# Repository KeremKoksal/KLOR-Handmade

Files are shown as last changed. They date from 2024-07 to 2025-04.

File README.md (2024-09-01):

# Welcome to my take on the great KLOR Split Keyboard Project
Here you'll find an up do date version of KLOR PCB and firmware files for Rev 1.4 for full height Cherry switches and a Rev 1.4 LP KS33 version for low profile KS33 Gateron switches.

If you intend to build a KLOR keyboard from this repo please take the time to read the different sections below.

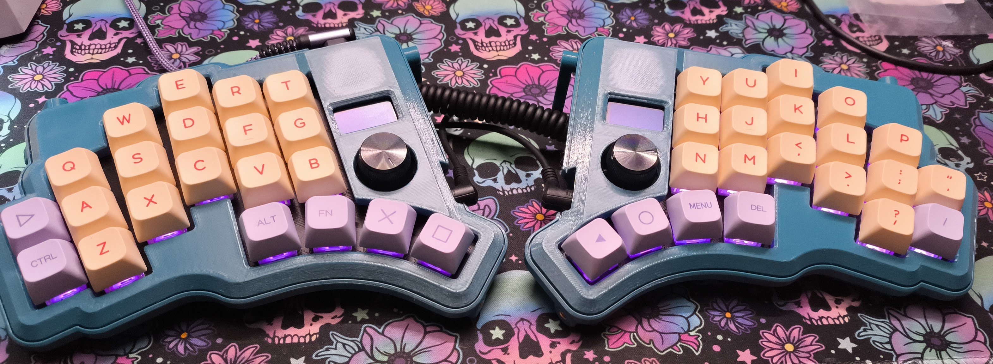
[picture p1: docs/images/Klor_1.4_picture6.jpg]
KLOR

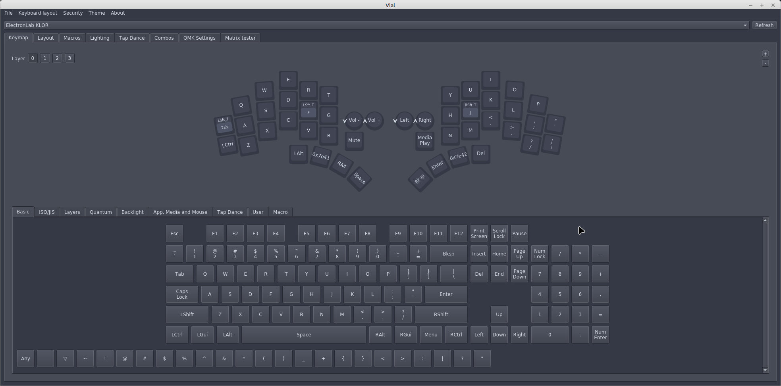
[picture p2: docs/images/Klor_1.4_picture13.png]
KLOR


### [CHANGELOG](https://github.com/Lefuneste83/KLOR/blob/main/CHANGELOG.md)

### [PCB FOR FULL HEIGHT SWITCHES (REV 1.4)](https://github.com/Lefuneste83/KLOR/tree/main/PCB/klor1_4)
-  This is my original initial design, derived from the 1.3 with lots of upgrades. I have built it and it works great. The south facing LED and the better suited LED packages make this the best choice for a first KLOR build. It keeps the overall design of the original in terms of PCB size and modularity. It is designed for MX style full height hotswap sockets. Gateron or Kailh sockets work great and probably other brands as well. This is not compatible with low profile sockets!

### [FABRICATION NOTES (FOR REV 1.4)](https://github.com/Lefuneste83/KLOR/blob/main/FABNOTES.md)
- These are my recommendations for first time builders of the KLOR keyboard. I suggest to have a read as they explain most tricky points that I have encountered while building mine.

### [PCB FOR LOW PROFILE GATERON KS33 SWITCHES (BETA VERSION REV 1.4 LP KS33)](https://github.com/Lefuneste83/KLOR/tree/main/PCB/klor1_4_LP_KS33)
-  This is a beta version derived from the 1.4 using low profile Gateron hotswap sockets for KS33 switches. It is a beta version so it will see lots of updates in the coming days. Don't rush to have it made except if you want to test it. In particular the haptic module will most likely interfere with the sockets and will require some filing of the haptic PCB. So it is not perfect yet.

### [PCB FOR ALTERNATIVE HAPTIC MODULE](https://github.com/Lefuneste83/KLOR/tree/main/PCB/Alternate%20DIY%20Haptic%20Module)
-  This is an alternative version of the haptic module for those who don't want to spend a fortune on the original one or can't source it. It is for advanced users as you will need some experience in SMD soldering and a hot air or hot plate to solder the linear actuator, and some form of magnification for the driver chip. It works great and is a bit shorter for easier integration. It mounts perfectly on all PCB versions except most likely on the low profile PCB because of the interference with the hotswap socket.

### [PCB FOR FULL HEIGHT SWITCHES CORRECTED STOCK VERSION (REV 1.3)](https://github.com/Lefuneste83/KLOR/tree/main/PCB/klor1_3)
-  This is as close as it gets to the original design but with some rerouting to allow to pass JLCPCB preproduction validation process. It uses the older style of LED (WS2812 3535) which are very tricky to solder properly, as they are not intended to be mounted this way. I strongly suggest moving to the 1.4 version for a much better build experience and a much more reliable build.

### [FIRMWARE](https://github.com/Lefuneste83/KLOR/blob/main/FIRMWARE.md)
-  VIAL support is now working on RP2040 with VIAL-QMK
-  These are updated QMK and ZMK config files and compiled images. They should have most devices enabled by default and should compile on latest toolchains of ZMK and QMK. A [Github Actions repositiry for ZMK](https://github.com/Lefuneste83/zmk-config-klor) is also available in my other repositories. Keep in mind that I only use ZMK on NRF52840 and QMK on RP2040. I would advise you to do the same as Atmega chips will not support all functionalities of the KLOR keyboard. As a reminder ZMK on NRF52840 will not support audio or haptic yet, but will support OLED to a certain degree and wireless communications with BLE protocol. QMK on RP2040 will support everything except wireless communications.

# CONTEXT
I have just completed my build of the 1.3 and found it a bit frustrating to assemble, despite my 13 year experience with this kind of project. Don't get me wrong the KLOR project is absolutely marvelous, but the PCB design starts to show its age IMHO, in the details of the layout in particular. Technology wise it is one, if not the best project out there hands down.

So here you will find a completely refactored PCB design of the KLOR project for 2024 including :

- Much better suited and easier to solder ARGB modules. I have used SK6812 Mini-E (aka 6028 size LED) version as it is the typical choice for this kind of keyboard application. I have thus kept the original paradigm of through hole design, with a symetrical front/back layout, but while using a LED module which is designed for this application, contrary to the original model WS2812 3535 which required a direct "hanged" soldering, with very likely damages to the plastic package as well as missalignment issues, as this part is designed for direct surface mount. I personnaly think that it would be even better to use the new WS2812 2020 package which is very neat, but as this is a strictly SMD part, there is no need for discrete cutouts anymore, so the design would look a bit different. Also you need to master SMD soldering. Let me know if you are interested in this type of LED package, I could make a forked design without too much fuss.

- As Hipyo Tech can confirm, we are in 2024 so no North facing LED are allowed anymore. I have moved to South facing LED.

- I have tried to keep the overall design paradigm so all the good stuff is still there!!

- I have very extensively refactored the PCB layout (3 days of intense work) to clean up the various little issues that were sprinkled around the original design including :

  Rerouting of 90% of the PCB. Healthier and more rational overall routing, at least that's my belief...
  
  Change to the footprint of the solder jumpers to triangular shapes much easier to bridge
  
  Correction of missing ground connections on the various switches bodies
  
  Dual ground planes thorough validation (this was painful)
  
  Very slight changes to the board cutout on the right side, to deal with reversed switch placement. Also very slight reduction of the cutout under the top of the MCU to catter some track celearance that would pop up in DRC. This should have no impact as this cutout serves no real purpose as far as I know. Cases and switchboards should mount the same, except for the ones using the puck cutout (see below).
  
  Very slight movement of the puck mounting holes downward (98.57 mm instead of 96.4 mm) by a couple milimeters to catter for reversed switches pad postions. I could not do otherwise without revisiting the switch layouts. I could not solve this by rotating the 3 mounting holes without interfering with other nets. It should not affect the mounting ability of the puck itself, but it WILL interfere with existing back cases using the puck cutout. So we will need specific cutouts for the case. As I don't have access to the original step model the best option would be to use some alternate case design provided with source files in order to lower the cutout by the same amount (2.17 mm).
  
  I managed a 0 error JLCPCB DRC, with only very few voluntary exceptions (down from 1000+). It took me several hours to clean up the various little issues that were sprinkled all around the orignial design. And I can confirm that Kicad on Linux is not a pleasure to use...
  
  Change of Logo with mine !

  This repo will be updated as I have new ideas for integrations of various tech or correction for errors.

  I have also included files for a working 1.3 design which passes the JLCPCB fabrication and is working as a real world product (REV 1.3)
  
***

<picture>
  <source media="(prefers-color-scheme: dark)" srcset="/docs/images/klor-font-logo-dark.svg">
  <source media="(prefers-color-scheme: light)" srcset="/docs/images/klor-font-logo-bright.svg">
  KLOR logo font
</picture>

# KLOR SPLIT KEYBOARD

KLOR is a 36-42 key column-staggered split keyboard. It supports a per-key RGB matrix, encoders, OLED displays, haptic feedback, speakers, a Pixart Paw3204 trackball, the [SplitKB tenting puck](https://splitkb.com/products/tenting-puck), and four different layouts, through break-off parts.

***

## RENDERING OF THIS FORK (Rev 1.4)

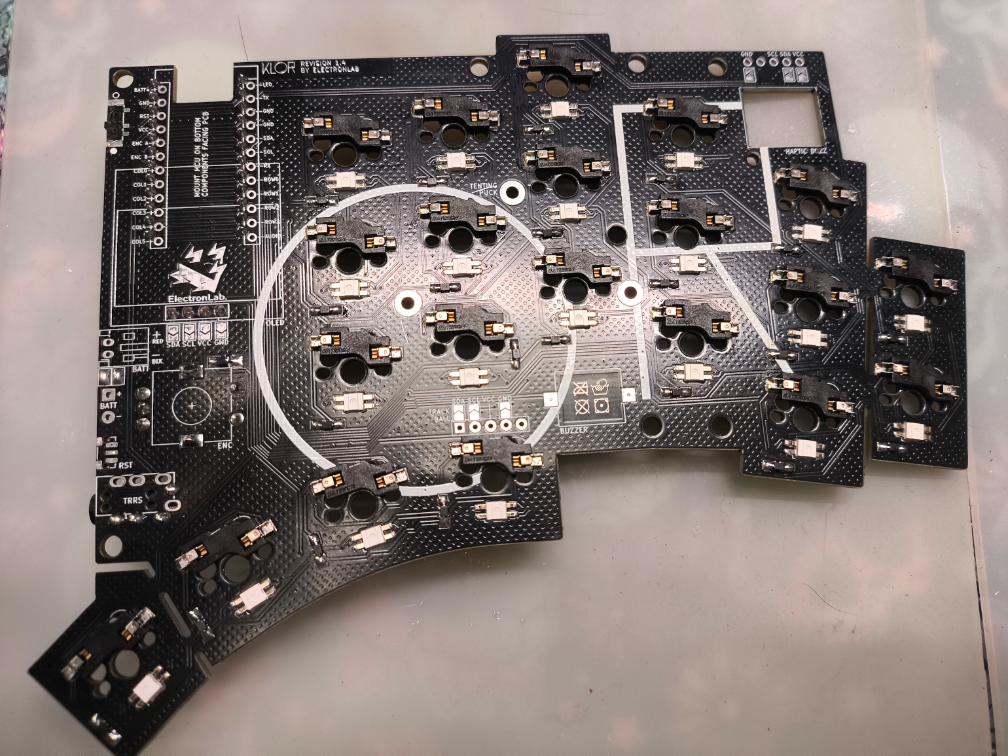
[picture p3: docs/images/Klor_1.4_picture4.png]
KLOR layouts

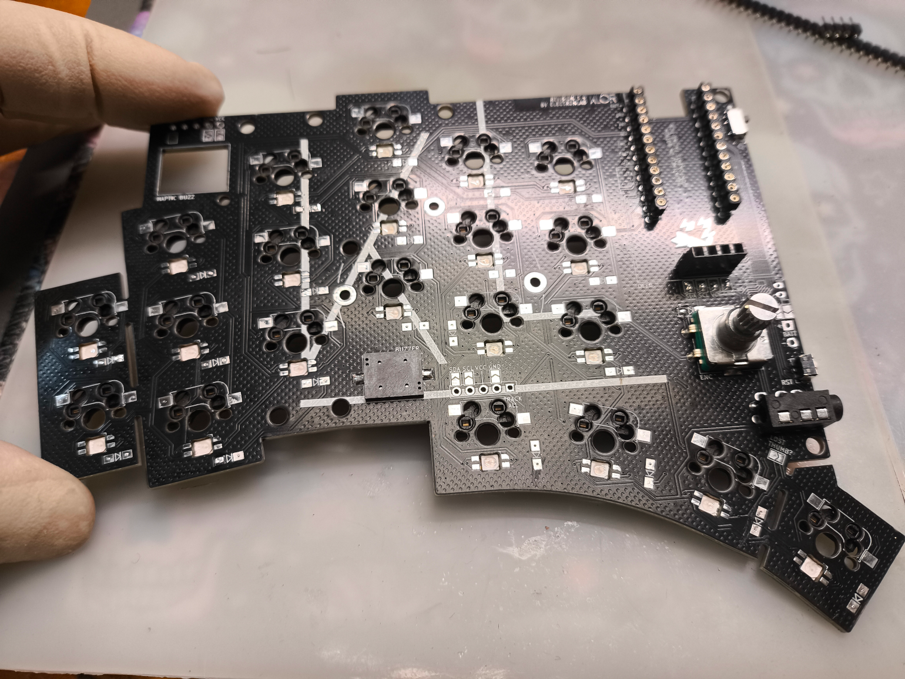
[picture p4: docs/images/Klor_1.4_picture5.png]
KLOR layouts

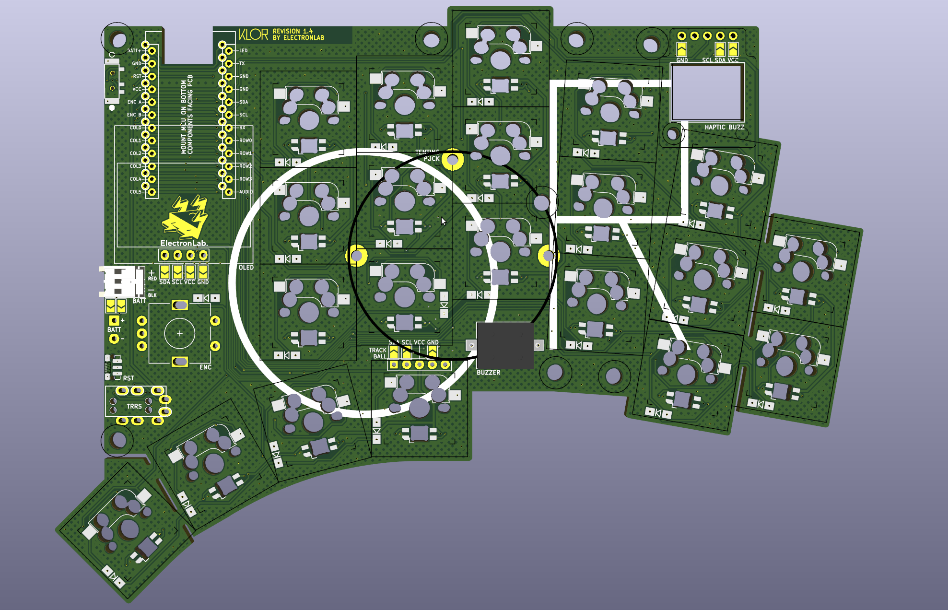
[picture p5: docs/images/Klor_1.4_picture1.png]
KLOR layouts

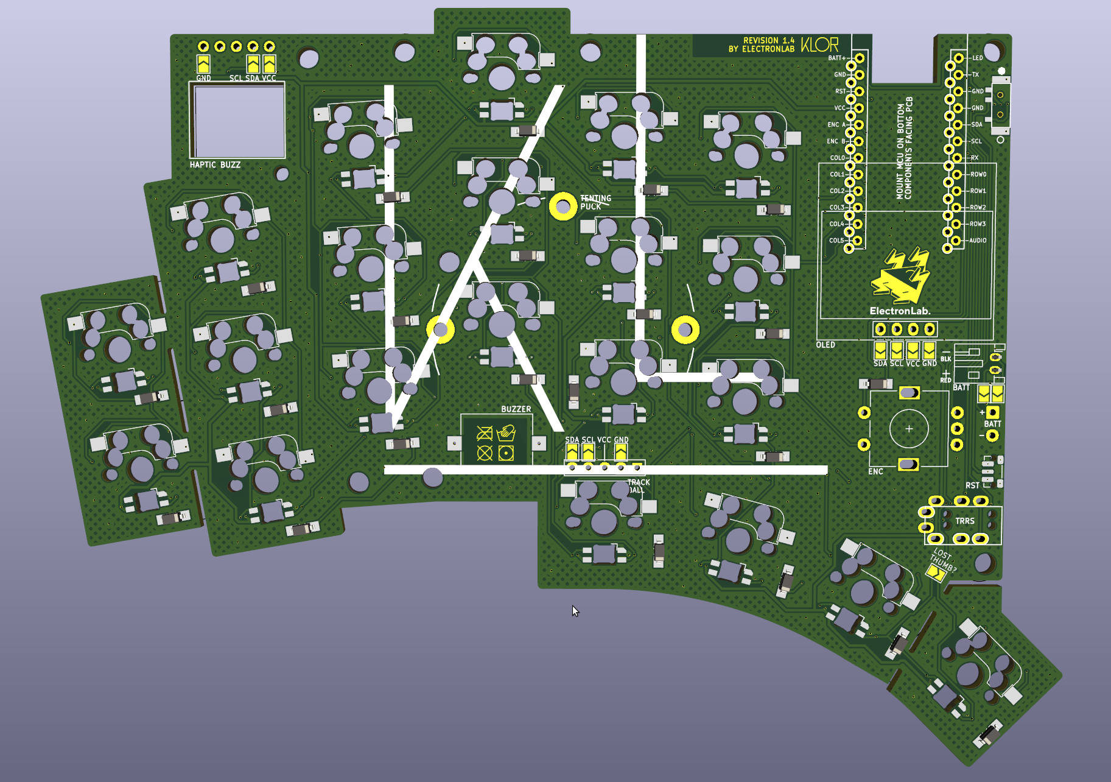
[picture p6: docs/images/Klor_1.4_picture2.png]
KLOR layouts

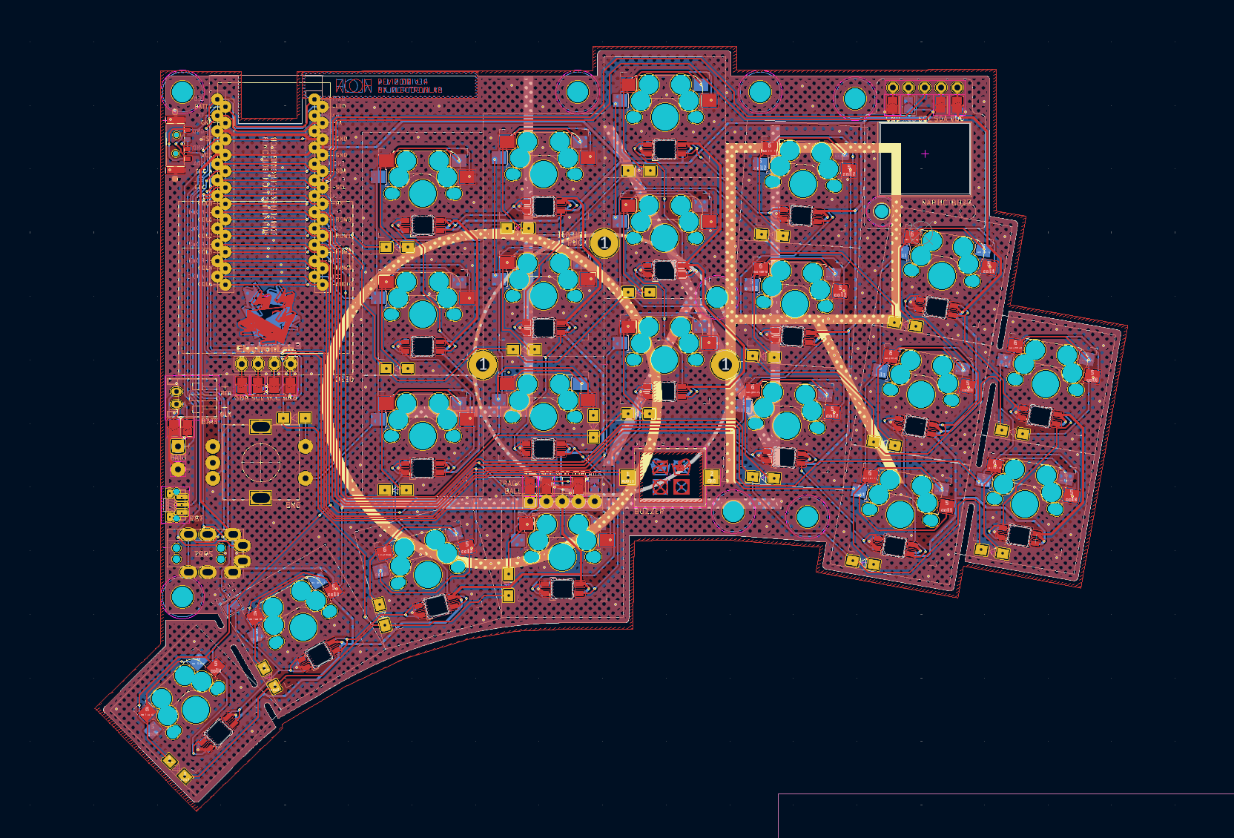
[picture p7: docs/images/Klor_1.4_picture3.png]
KLOR layouts


***

## LAYOUTS

KLOR layouts

***

## PCB 

[Here](/PCB/) you can find the KiCad files and Gerbers for the KLOR 1.3 (tested working with JLCPCB) and 1.4 (this version). 

***

## CASE

[Here](/case/) are the case files for the KLOR. There is an acrylic case and a 3D printed case (which uses acrylic too) for every layout.

***

## SWITCHPLATE

In every case directory you'll find the matching switchplates as **.dxf**, **.svg**, **.stl**, and a **.zip**-file, containing gerber files for a FR4 plate.

***

## KNOB

You can use pretty much any knob, which works with the EC11 encoder, but [here](/knob/) you can find one, I designed for the KLOR.

***

## BUILD GUIDE

Here you can find the build guides for the KLOR.\
[KLOR build guide 3DP case](/docs/buildguide_3DP.md) (QMK)\
[KLOR build guide stacked acrylic case](/docs/buildguide_acrylic.md) (QMK)\
[KLOR BLE build guide 3DP case](/docs/buildguide_3DP_ble.md) (ZMK)\
[KLOR BLE build guide stacked acrylic case](/docs/buildguide_acrylic_ble.md) (ZMK)

***

## CHOC/KS27 VERSION

[Sadek Baroudi](https://github.com/sadekbaroudi) did an amazing job in creating a version of the KLOR which supports KS-27 and Choc V1 switches. Including a special case for it.\
[KLOR Sadek KS-27 and Choc V1 mod](https://github.com/sadekbaroudi/KLOR)

***

## CREDITS

The KLORs hardware is based on the [Sofle](https://github.com/josefadamcik/SofleKeyboard) by [Josef Adamcik](https://github.com/josefadamcik).\
Other inspirations are 
- [Kyria](https://splitkb.com/products/kyria-pcb-kit) by [Thomas Baart](https://github.com/splitkb)
- [Yacc46](https://github.com/1m38/keyboards/tree/main/yacc46) by [1m38](https://github.com/1m38)
- [Elephant42](https://github.com/illness072/elephant42) by [illness072](https://github.com/illness072)
- [Torn](https://github.com/rtitmuss/torn) by [Richard Titmuss](https://github.com/rtitmuss)
- [Claw44](https://github.com/yfuku/claw44) by [yfuku](https://github.com/yfuku)

I used the Pimoroni Haptic Buzz Footprint from the [Buzzard](https://github.com/crehmann/Buzzard) by [Christoph Rehmann](https://github.com/crehmann).

***

People who helped me create this board and fix stuff
- [KarlK90](https://github.com/KarlK90)
- [MangoIV](https://github.com/MangoIV)
- [OxCB](https://github.com/0xCB-dev)
- [MicroFortnight](https://github.com/microfortnight)
- [dreipunkteinsvier](https://github.com/dreipunkteinsvier)

If you build a KLOR I would be pretty happy to see some pictures. And if you want to leave me a tip you can do this [here](https://ko-fi.com/geigeigeist) (but please don't feel pressured)

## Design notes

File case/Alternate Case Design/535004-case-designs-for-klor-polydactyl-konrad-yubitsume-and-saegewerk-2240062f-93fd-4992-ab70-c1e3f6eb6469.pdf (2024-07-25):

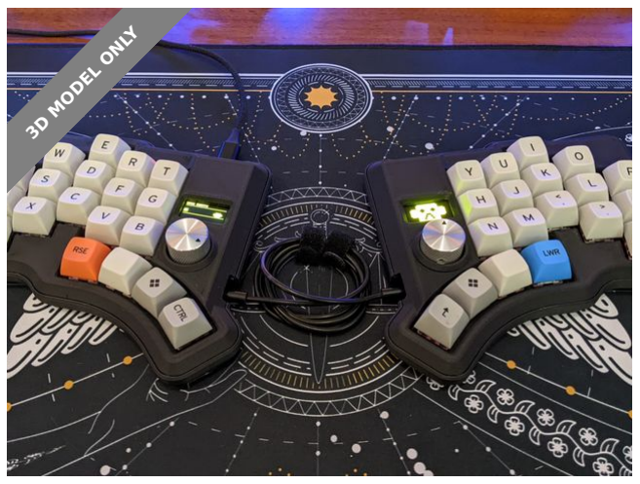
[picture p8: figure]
3D MODEL ONLY

## Summary

This is a case design for all four variants of the KLOR by GEIST

Gadgets (https://printables.com/model?categoryId=21) > Other Gadgets (https://printables.com/model?categoryId=43)

These are gasket mount case designs with optional tenting for KLOR. All four variants are supported. The top and bottom pieces fasten with 6mm x 3mm neodymium magnets. The optional tenting fastens via M3 heatset inserts. The lid pieces support encoder knobs up to 24mm. There are encoder inserts to accommodate knobs of a smaller diameter (20mm and 16mm).

IMPORTANT: The case design requires the MCU be mounted on TOP of the PCB with its components facing up. MCU sockets are recommended. The OLED screens were mounted with IC SIP sockets to allow it to be mounted low enough to fit in the case. Some low profile MCU sockets would also suffice.

M3 Inserts: https://www.amazon.com/gp/product/B09ZNXRD2H/ref=ppx_yo_dt_b_search_asin_title?ie=UTF8&th=1 (https://www.amazon.com/gp/product/B09ZNXRD2H/ref=ppx_yo_dt_b_search_asin_title?ie=UTF8&th=1)

Magnets: https://www.amazon.com/DIYMAG-6x3mm-Refrigerator-Premium-Brushed/dp/B07KZQGWNN (https://www.amazon.com/DIYMAG-6x3mm-Refrigerator-Premium-Brushed/dp/B07KZQGWNN)

chewiedies (https://printables.com/@chewiedies_360738)

## Case designs for

KLOR (Polydactyl,
Konrad, Yubitsume,

## and Saegewerk,)

VIEW IN BROWSER (https://printables.com/model/535004-case-designs-for-klor-polydactyl-konrad-yubitsume)

updated 2. 7. 2024 | published 2. 7. 2024

## Model files

3mm Foam: https://www.amazon.com/Neoprene-Adhesive-Padding-Multi-Function-Soundproof/dp/B08RB2FWVR/?th=1 (https://www.amazon.com/Neoprene-Adhesive-Padding-Multi-Function-Soundproof/dp/B08RB2FWVR/?th=1)

1mm Foam: https://www.amazon.com/gp/product/B07L6KV4QG/ref=ppx_yo_dt_b_search_asin_title?ie=UTF8&psc=1 (https://www.amazon.com/gp/product/B07L6KV4QG/ref=ppx_yo_dt_b_search_asin_title?ie=UTF8&psc=1)

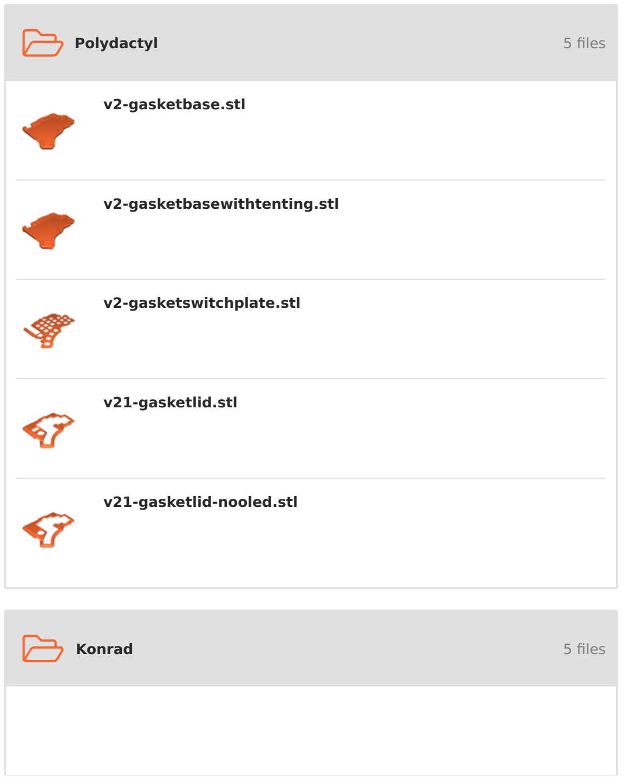
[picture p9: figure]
Polydactyl; 5 files; Konrad; v2-gasketbase.stl; v2-gasketbasewithtenting.stl; v2-gasketswitchplate.stl; v21-gasketlid.stl; v21-gasketlid-nooled.stl

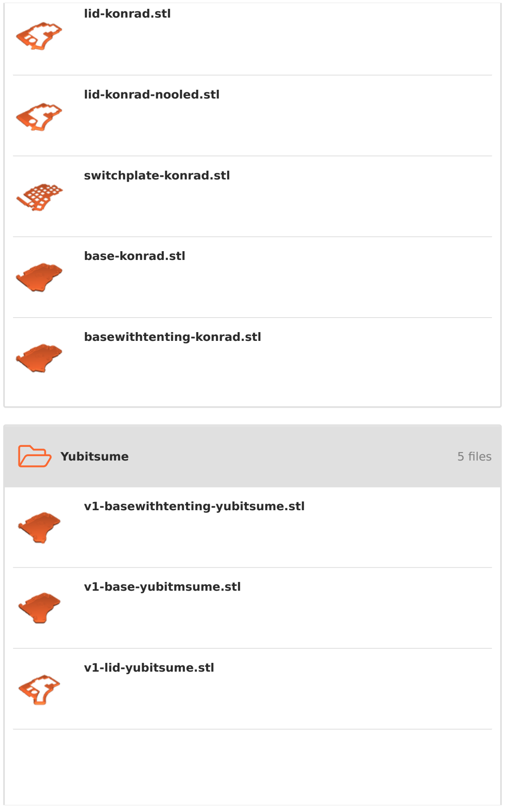
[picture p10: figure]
Yubitsume; 5 files; lid-konrad.stl; lid-konrad-nooled.stl; switchplate-konrad.stl; base-konrad.stl; basewithtenting-konrad.stl; v1-basewithtenting-yubitsume.stl; v1-base-yubitmsume.stl; v1-lid-yubitsume.stl

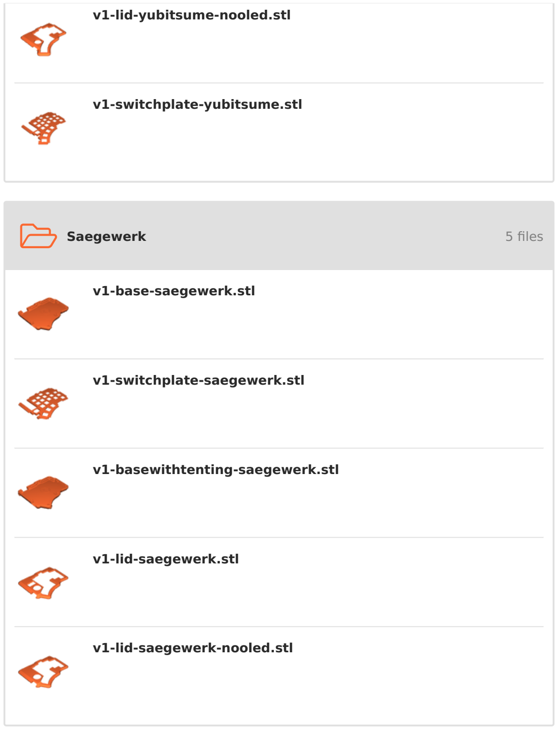
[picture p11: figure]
Saegewerk; 5 files; v1-lid-yubitsume-nooled.stl; v1-switchplate-yubitsume.stl; v1-base-saegewerk.stl; v1-switchplate-saegewerk.stl; v1-basewithtenting-saegewerk.stl; v1-lid-saegewerk.stl; v1-lid-saegewerk-nooled.stl

encoderinsert-flat-16mm.stl

## License

This work is licensed under a
Creative Commons (4.0 International License)

Attribution—Noncommercial—Share Alike (http://creativecommons.org/licenses/by-nc-sa/4.0/)

✖ | Sharing without ATTRIBUTION
✔ | Remix Culture allowed
✖ | Commercial Use
✖ | Free Cultural Works
✖ | Meets Open Definition

encoderinsert-flat.stl

encoderinsert-16mm.stl

encoderinsert.stl

klor-case-designs-v52.step

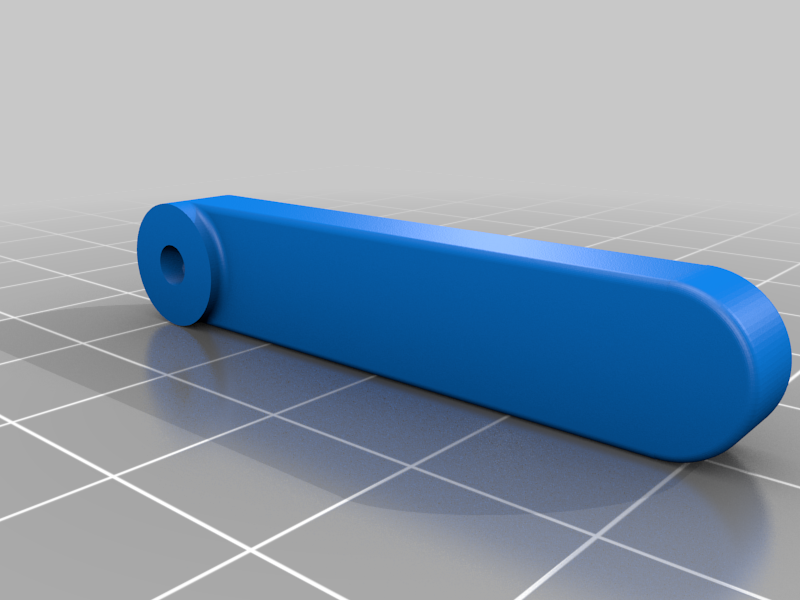
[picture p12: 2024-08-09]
case/Alternate Case Design/Tenting Legs/images/tentingLeg42mm.png

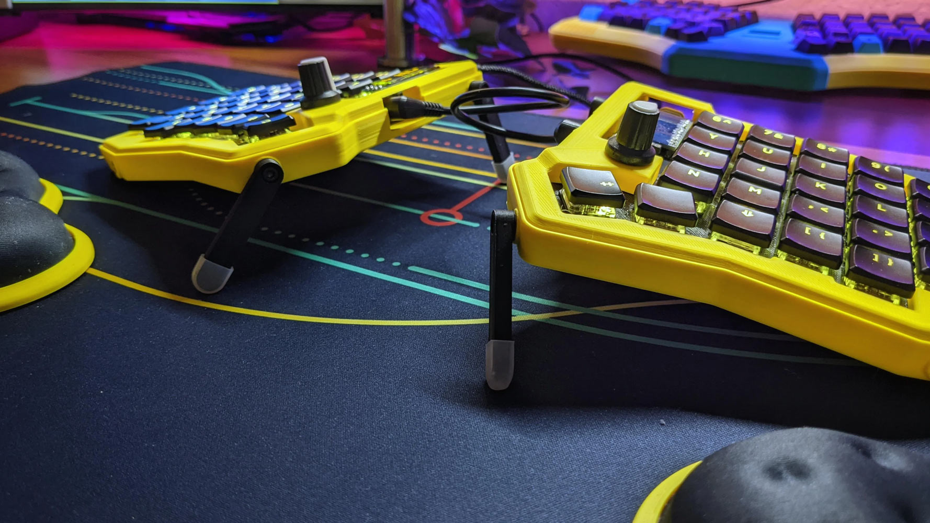
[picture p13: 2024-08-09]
case/Alternate Case Design/Tenting Legs/images/choc-sofle-2.jpg

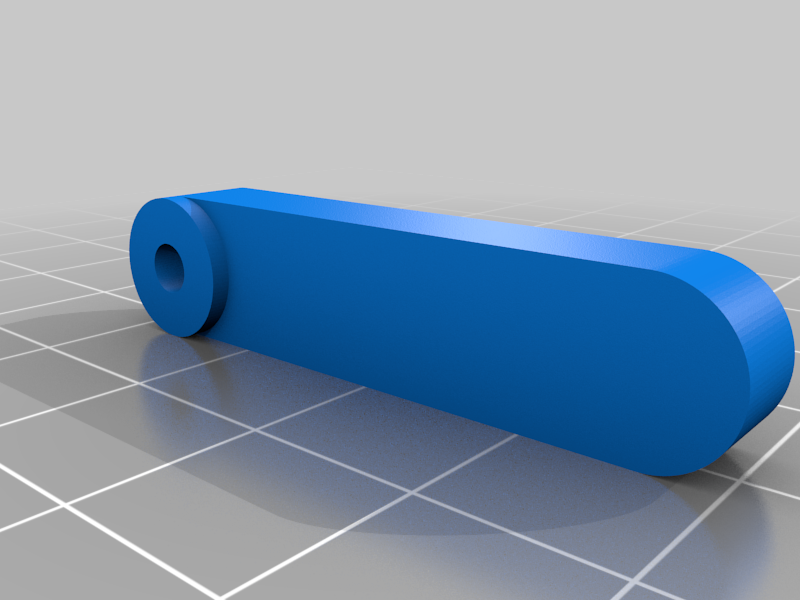
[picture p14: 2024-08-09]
case/Alternate Case Design/Tenting Legs/images/tentingleg36mm.png

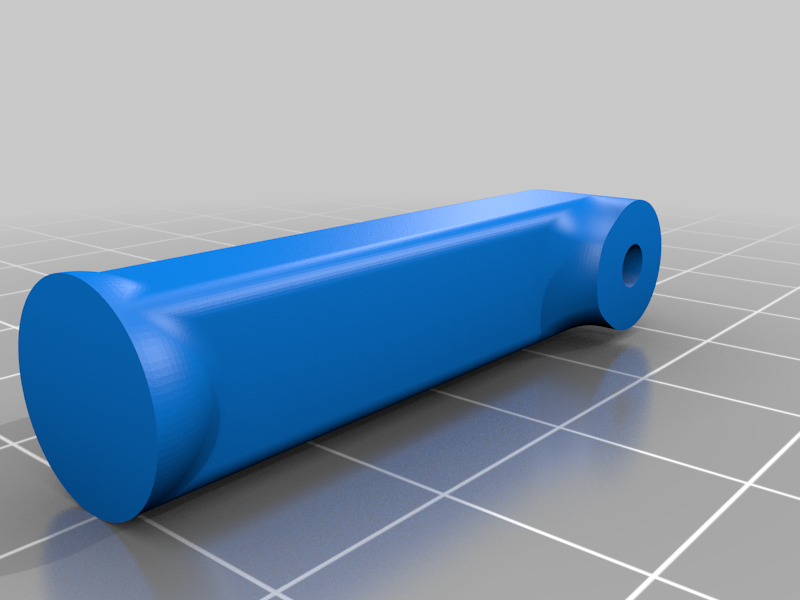
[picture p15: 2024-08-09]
case/Alternate Case Design/Tenting Legs/images/tentingLegALT37mm.png

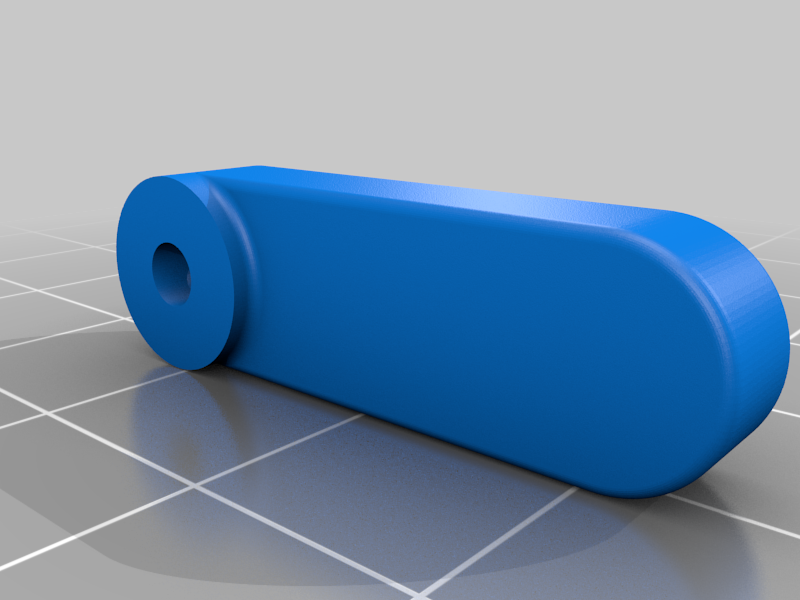
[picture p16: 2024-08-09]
case/Alternate Case Design/Tenting Legs/images/tentingLeg26mm.png

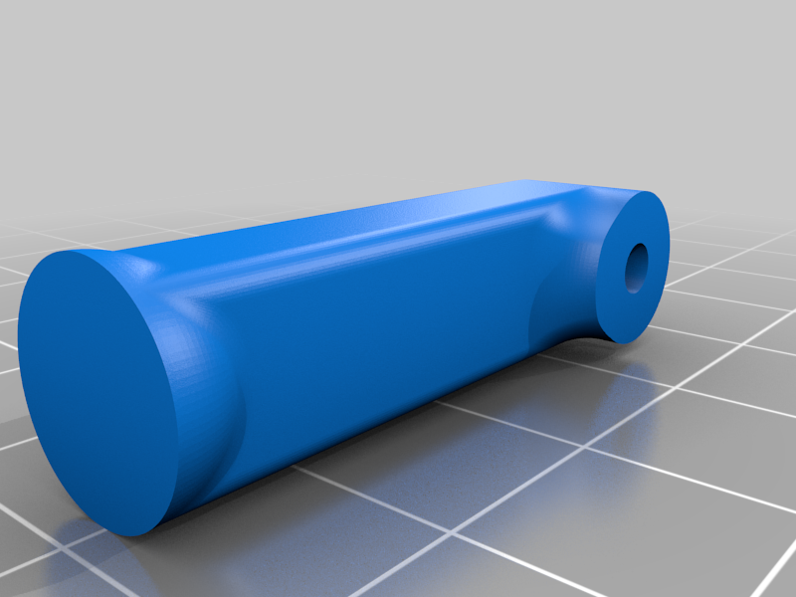
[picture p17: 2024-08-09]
case/Alternate Case Design/Tenting Legs/images/tentingLegALT31mm.png

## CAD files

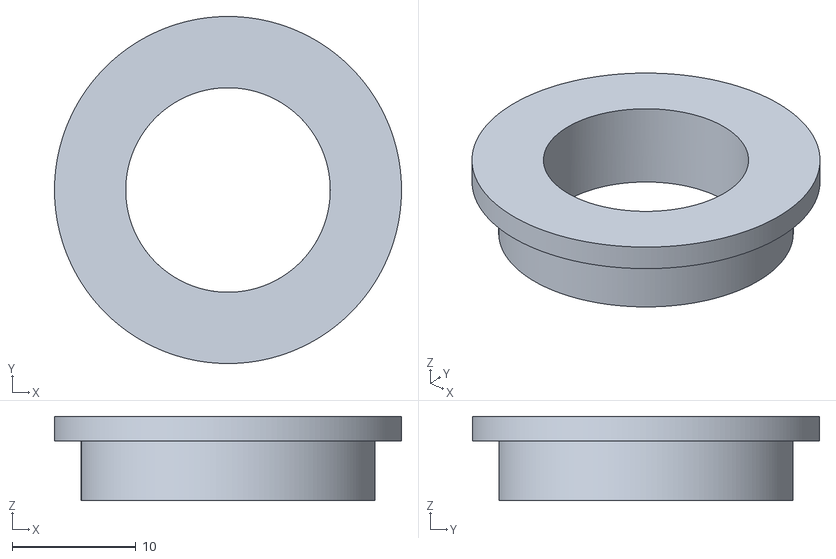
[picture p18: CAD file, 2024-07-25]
case/Alternate Case Design/EncoderInsert-flat-16mm.stl
28.0 x 28.0 x 6.80

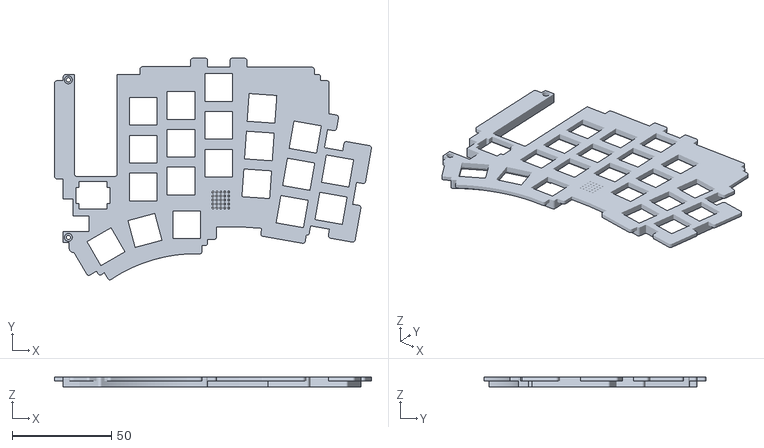
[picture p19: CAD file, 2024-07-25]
case/Alternate Case Design/Konrad/SwitchPlate-Konrad.stl
159.8 x 111.8 x 5.00

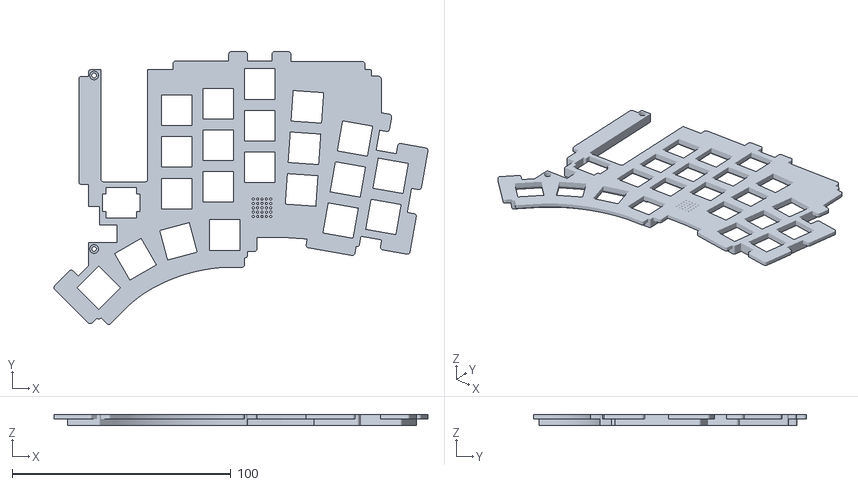
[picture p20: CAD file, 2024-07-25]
case/Alternate Case Design/Polydactyl/v2-GasketSwitchPlate.stl
171.1 x 124.9 x 5.00

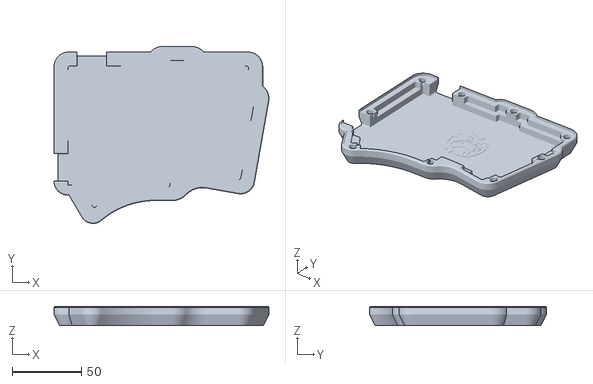
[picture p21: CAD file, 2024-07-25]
case/Alternate Case Design/Saegewerk/v1-Base-Saegewerk.stl
155.7 x 128.2 x 14.0

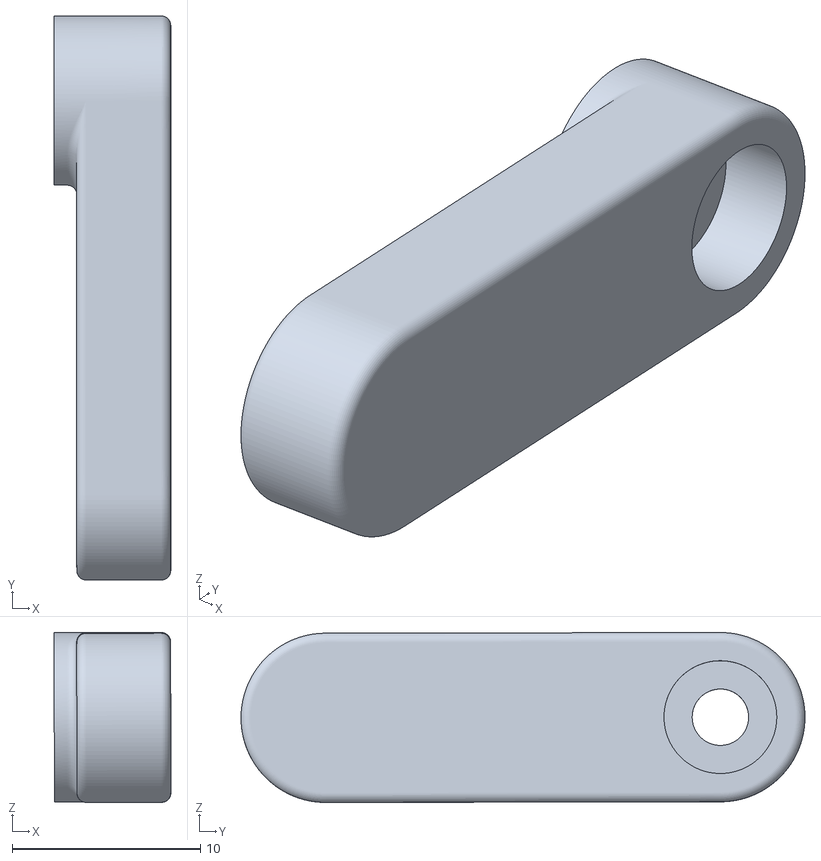
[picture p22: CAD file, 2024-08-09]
case/Alternate Case Design/Tenting Legs/files/tentingLeg26mm.stl
6.21 x 30.0 x 9.04

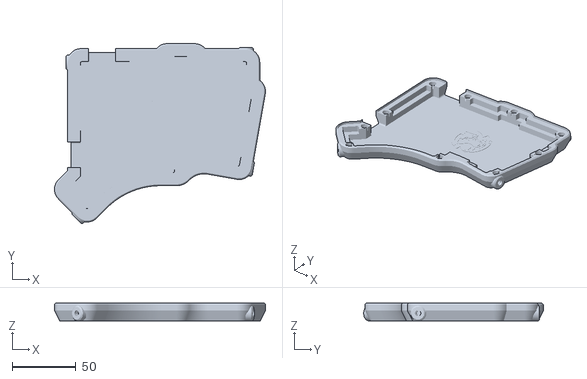
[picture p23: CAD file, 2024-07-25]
case/Alternate Case Design/Yubitsume/v1-BaseWithTenting-Yubitsume.stl
165.8 x 141.2 x 14.0

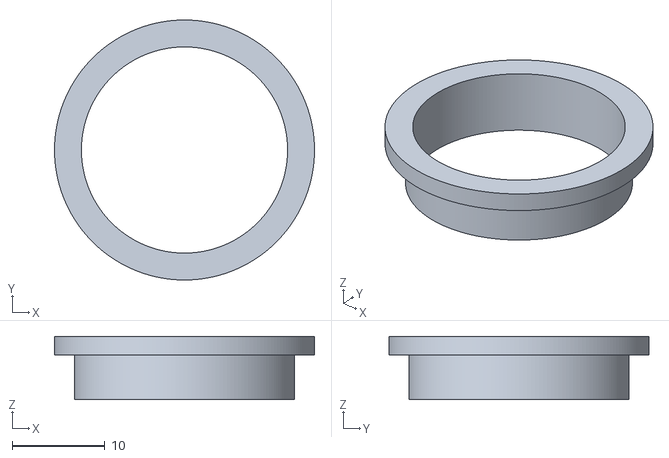
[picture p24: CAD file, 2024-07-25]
case/Alternate Case Design/EncoderInsert-flat.stl
28.0 x 28.0 x 6.80

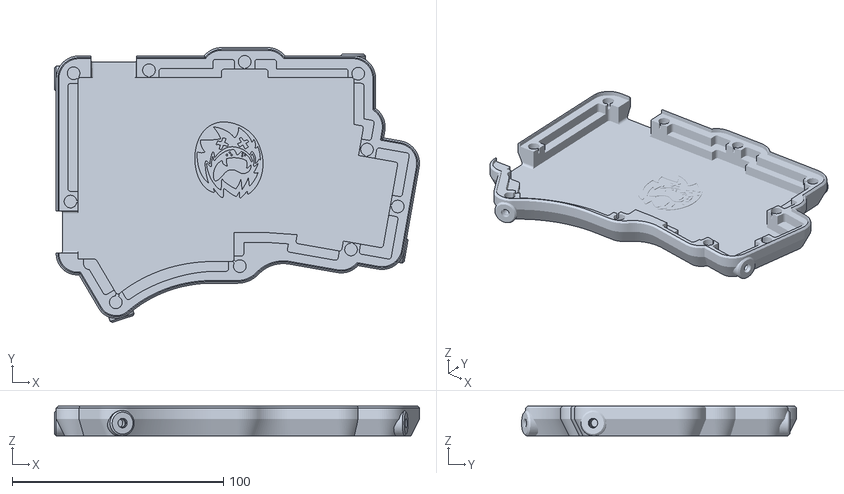
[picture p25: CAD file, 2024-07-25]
case/Alternate Case Design/Konrad/BaseWithTenting-Konrad.stl
172.8 x 130.1 x 14.0

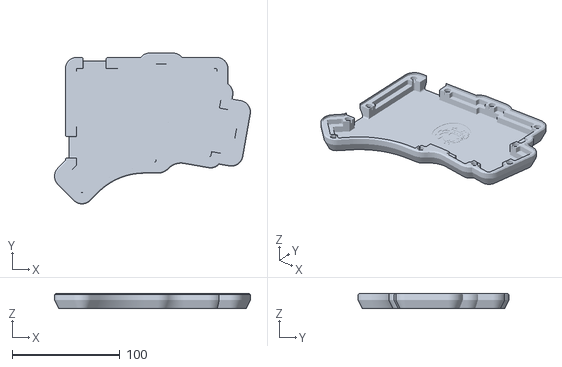
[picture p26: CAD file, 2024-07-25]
case/Alternate Case Design/Polydactyl/v2-GasketBase.stl
182.0 x 140.1 x 14.0

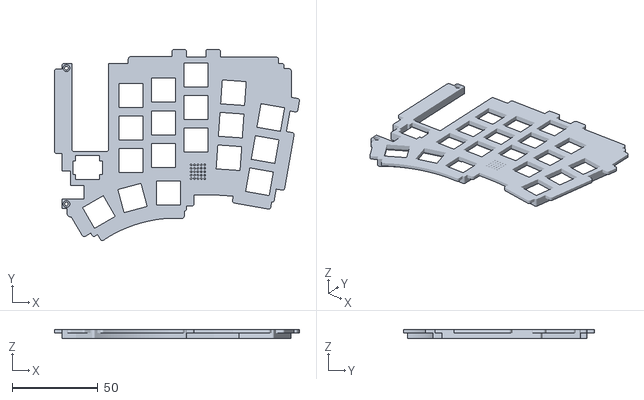
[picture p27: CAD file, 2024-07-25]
case/Alternate Case Design/Saegewerk/v1-SwitchPlate-Saegewerk.stl
143.2 x 111.8 x 5.00

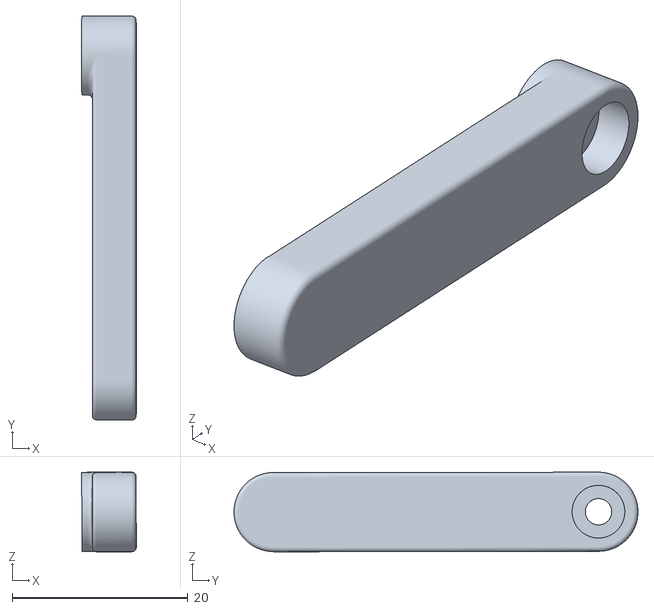
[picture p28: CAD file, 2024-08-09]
case/Alternate Case Design/Tenting Legs/files/tentingLeg42mm.stl
6.21 x 46.0 x 9.07

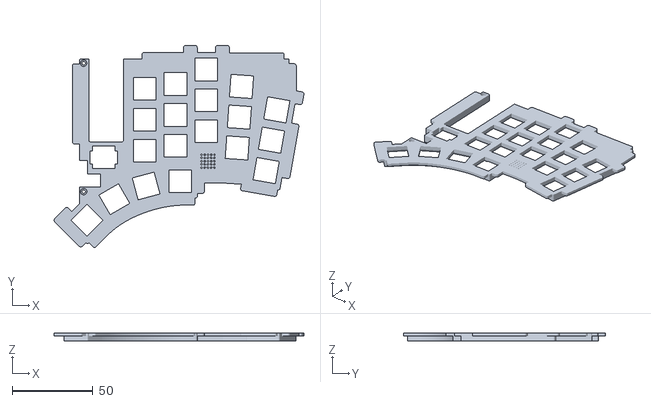
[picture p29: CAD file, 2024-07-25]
case/Alternate Case Design/Yubitsume/v1-SwitchPlate-Yubitsume.stl
154.6 x 124.9 x 5.00

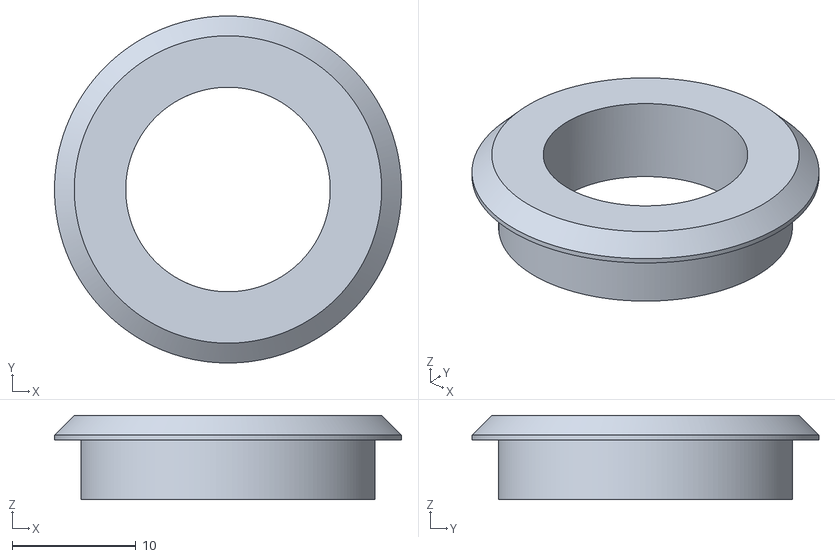
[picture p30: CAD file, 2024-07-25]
case/Alternate Case Design/EncoderInsert-16mm.stl
28.0 x 28.0 x 6.80

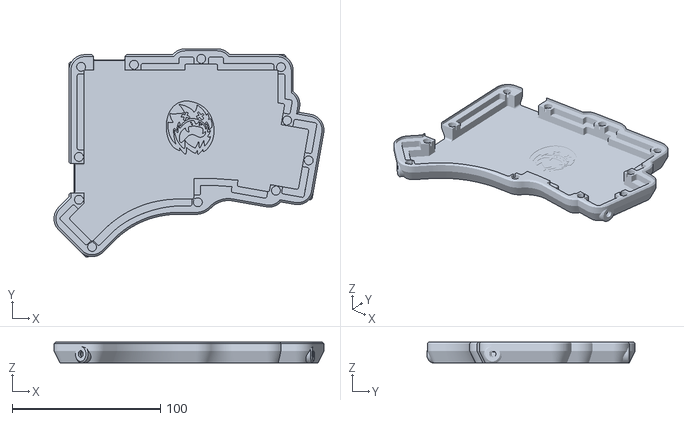
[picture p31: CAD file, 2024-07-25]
case/Alternate Case Design/Polydactyl/v2-GasketBaseWithTenting.stl
182.0 x 140.5 x 14.0

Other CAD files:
case/Alternate Case Design/Konrad/Base-Konrad.stl
case/Alternate Case Design/Saegewerk/v1-BaseWithTenting-Saegewerk.stl
case/Alternate Case Design/Tenting Legs/files/tentingleg36mm.stl
case/Alternate Case Design/Yubitsume/v1-Lid-Yubitsume-noOLED.stl
case/Alternate Case Design/EncoderInsert.stl
case/Alternate Case Design/Tenting Legs/files/TentingLeg38mm.stl
case/Alternate Case Design/Tenting Legs/files/tentingLeg40mm.stl
case/Alternate Case Design/Tenting Legs/files/tentingLegALT31mm.stl
case/Alternate Case Design/Tenting Legs/files/tentingLegALT37mm.stl
case/Alternate Case Design/Yubitsume/v1-Base-Yubitmsume.stl
case/Alternate Case Design/Yubitsume/v1-Lid-Yubitsume.stl

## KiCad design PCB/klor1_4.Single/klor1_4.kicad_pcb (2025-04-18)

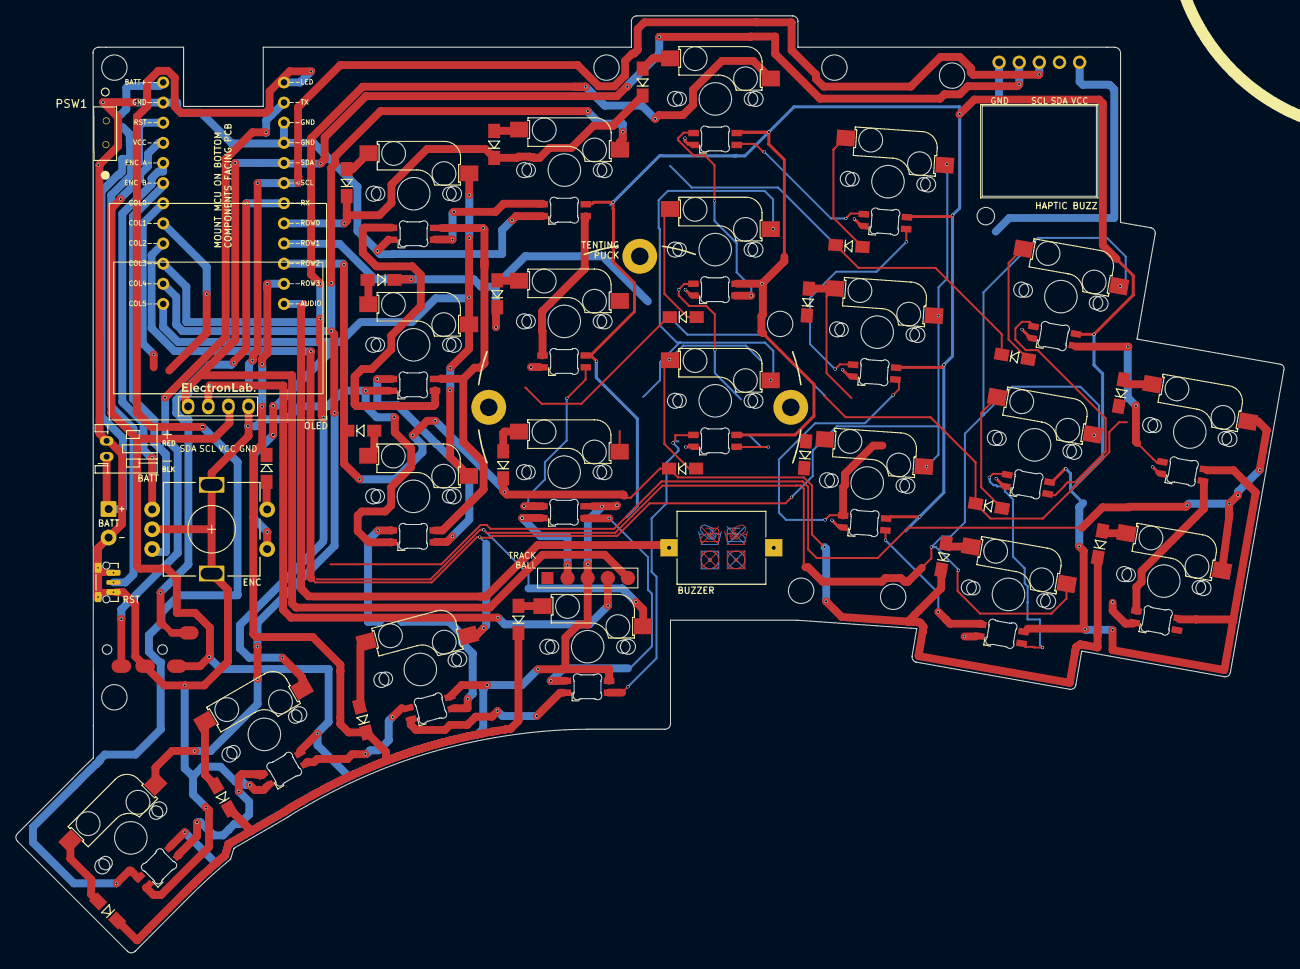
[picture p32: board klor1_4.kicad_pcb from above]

Board: 2 copper layers, 160.0 x 118.2 mm, 63 parts (1 on the bottom side), 65 nets.

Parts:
BT1: JST Connector; JST_PH_reversible
BT2: Battery_Cell; custombatteryconnector_small
BZ1: Buzzer; Buzzer_Mallory_AST1109MLTRQ_reversible
D1, D2, D3, D4, D5, D6, D7, D8, D9, D10, D11, D12, D13, D14, D15, D16, D17, D18, D19, D20, D21, D22: D_Small; Diode_SOD123
J1: MJ-4PP-9
J2: Haptic Buzz; Pimoroni Haptic Buzz DRV2605L Driver
J3: lv27; lvc27_onlyInput
MH1, MH2, MH3, MH4, MH5, MH6, MH7, MH8: MountingHole_3.2mm_M3
MH9: MountingHole_2.2mm_M2
OLED1: SSD1306; SSD1306_128x64OLED
PSW1: SW_DPDT_x2; MSK12C02_reversible
RSW1: SW_Push; SW_Push_1P1T-MP_NO_Horizontal_Alps_SKRTLAE010_both_sides
SW1, SW2, SW3, SW4, SW5, SW6, SW7, SW8, SW9, SW10, SW11, SW12, SW13, SW14, SW15, SW16, SW17, SW19, SW20, SW21, SW22: SW_PUSH-MX_W_LED; SK6812MINI_and_cherry_1
SW18: RotaryEncoder_Switch; RotaryEncoder_Alps_EC11E-Switch_Vertical_H20mm-keebio_modif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
U1: ProMicro_Single

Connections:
+BATT: PSW1.3 (C), U1.1
/PSW: BT1.1 (+), BT2.1 (+), PSW1.2 (B)
AUDIO: BZ1.1 (-), U1.13
ENCA: SW18.A, U1.5
ENCB: SW18.B, U1.6
GND: BT1.2 (-), BT2.2 (-), BZ1.2 (+), J1.2, J2.5, J3.2, OLED1.1 (GND), PSW1.NC, RSW1.1, RSW1.MP, SW1.2 (VSS), SW2.2 (VSS), SW3.2 (VSS), SW4.2 (VSS), SW5.2 (VSS), SW6.2 (VSS), SW7.2 (VSS), SW8.2 (VSS), SW9.2 (VSS), SW10.2 (VSS), SW11.2 (VSS), SW12.2 (VSS), SW13.2 (VSS), SW14.2 (VSS), SW15.2 (VSS), SW16.2 (VSS), SW17.2 (VSS), SW18.C, SW18.MP, SW19.2 (VSS), SW20.2 (VSS), SW21.2 (VSS), SW22.2 (VSS), U1.2, U1.21, U1.22
LED: SW19.3 (DIN), U1.24
unnamed: D1.2 (A), SW1.6
unnamed: D2.2 (A), SW2.6
unnamed: D3.2 (A), SW3.6
unnamed: D4.2 (A), SW4.6
unnamed: D5.2 (A), SW5.6
unnamed: D6.2 (A), SW6.6
unnamed: D7.2 (A), SW7.6
unnamed: D8.2 (A), SW8.6
unnamed: D9.2 (A), SW9.6
unnamed: D10.2 (A), SW10.6
unnamed: D11.2 (A), SW11.6
unnamed: D12.2 (A), SW12.6
unnamed: D13.2 (A), SW13.6
unnamed: D14.2 (A), SW14.6
unnamed: D15.2 (A), SW15.6
unnamed: D16.2 (A), SW16.6
unnamed: D17.2 (A), SW17.6
unnamed: D19.2 (A), SW19.6
unnamed: D20.2 (A), SW20.6
unnamed: D21.2 (A), SW21.6
unnamed: D22.2 (A), SW22.6
unnamed: SW1.3 (DIN), SW6.1 (DOUT)
unnamed: SW1.1 (DOUT), SW2.3 (DIN)
unnamed: SW2.1 (DOUT), SW7.3 (DIN)
unnamed: SW3.3 (DIN), SW8.1 (DOUT)
unnamed: SW3.1 (DOUT), SW4.3 (DIN)
unnamed: SW4.1 (DOUT), SW9.3 (DIN)
unnamed: SW10.3 (DIN), SW16.1 (DOUT)
unnamed: SW5.3 (DIN), SW10.1 (DOUT)
unnamed: SW5.1 (DOUT), SW11.3 (DIN)
unnamed: SW11.1 (DOUT), SW17.3 (DIN)
unnamed: SW12.3 (DIN), SW21.1 (DOUT)
unnamed: SW6.3 (DIN), SW12.1 (DOUT)
unnamed: SW7.1 (DOUT), SW13.3 (DIN)
unnamed: SW13.1 (DOUT), SW22.3 (DIN)
unnamed: SW14.3 (DIN), SW22.1 (DOUT)
unnamed: SW8.3 (DIN), SW14.1 (DOUT)
unnamed: SW9.1 (DOUT), SW15.3 (DIN)
unnamed: SW15.1 (DOUT), SW16.3 (DIN)
unnamed: SW19.1 (DOUT), SW20.3 (DIN)
unnamed: SW20.1 (DOUT), SW21.3 (DIN)
RESET: RSW1.2, U1.3
RX: J1.3, U1.18
SCL: J2.3, J3.4, OLED1.3 (SCL), U1.19
SDA: J2.2, J3.5, OLED1.4 (SDA), U1.20
SW18B: D18.2 (A), SW18.S2
TX: J1.4, U1.23
VCC: J1.1, J2.1, J3.3, OLED1.2 (VCC), SW1.4 (VDD), SW2.4 (VDD), SW3.4 (VDD), SW4.4 (VDD), SW5.4 (VDD), SW6.4 (VDD), SW7.4 (VDD), SW8.4 (VDD), SW9.4 (VDD), SW10.4 (VDD), SW11.4 (VDD), SW12.4 (VDD), SW13.4 (VDD), SW14.4 (VDD), SW15.4 (VDD), SW16.4 (VDD), SW17.4 (VDD), SW19.4 (VDD), SW20.4 (VDD), SW21.4 (VDD), SW22.4 (VDD), U1.4
col0: SW11.5, SW17.5, U1.7
col1: SW5.5, SW10.5, SW16.5, SW22.5, U1.8
col2: SW4.5, SW9.5, SW15.5, SW21.5, U1.9
col3: SW3.5, SW8.5, SW14.5, SW20.5, U1.10
col4: SW2.5, SW7.5, SW13.5, SW19.5, U1.11
col5: SW1.5, SW6.5, SW12.5, SW18.S1, U1.12
row0: D1.1 (K), D2.1 (K), D3.1 (K), D4.1 (K), D5.1 (K), U1.17
row1: D6.1 (K), D7.1 (K), D8.1 (K), D9.1 (K), D10.1 (K), D11.1 (K), U1.16
row2: D12.1 (K), D13.1 (K), D14.1 (K), D15.1 (K), D16.1 (K), D17.1 (K), U1.15
row3: D18.1 (K), D19.1 (K), D20.1 (K), D21.1 (K), D22.1 (K), U1.14

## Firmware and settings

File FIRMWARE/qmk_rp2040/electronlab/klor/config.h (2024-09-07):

/*
Copyright 2024 ElectronLab

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
You should have received a copy of the GNU General Public License
along with this program.  If not, see <http://www.gnu.org/licenses/>.
*/

#pragma once


// ┌─────────────────────────────────────────────────┐
// │ p i n   c o n f i g                             │
// └─────────────────────────────────────────────────┘ 

#define I2C1_SCL_PIN GP3
#define I2C1_SDA_PIN GP2

// ┌─────────────────────────────────────────────────┐
// │ k e y   m a t r i x                             │
// └─────────────────────────────────────────────────┘ 

//#define MATRIX_ROW_PINS { GP5, GP6, GP7, GP8 }
//#define MATRIX_COL_PINS { GP27, GP26, GP22, GP20, GP23, GP21 }
//#define DIODE_DIRECTION COL2ROW
#define MATRIX_ROWS 8
#define MATRIX_COLS 6
#define DEBOUNCE 5


// ┌─────────────────────────────────────────────────┐
// │ s p l i t   c o m m u n i c a t i o n           │
// └─────────────────────────────────────────────────┘ 

#define USE_SERIAL
#define SERIAL_USE_MULTI_TRANSACTION
#define SPLIT_USB_DETECT

//Half Duplex communication
#define SERIAL_USART_TX_PIN GP1     // USART TX pin

//Full Duplex communication
//#define SERIAL_USART_TX_PIN GP4     // USART TX pin
//#define SERIAL_USART_RX_PIN GP1     // USART RX pin
//#define SERIAL_USART_FULL_DUPLEX
//#define SERIAL_USART_PIN_SWAP

// ┌─────────────────────────────────────────────────┐
// │ e n c o d e r s                                 │
// └─────────────────────────────────────────────────┘ 

//#define ENCODERS_PAD_A       { GP28 }
//#define ENCODERS_PAD_B       { GP29 }
//#define ENCODERS_PAD_A_RIGHT { GP29 }
//#define ENCODERS_PAD_B_RIGHT { GP28 }
#define ENCODER_RESOLUTION { 2 }
#define ENCODER_RESOLUTIONS_RIGHT { 2 }


// ┌─────────────────────────────────────────────────┐
// │ o l e d s                                       │
// └─────────────────────────────────────────────────┘

#ifdef OLED_ENABLE
#    define OLED_DISPLAY_128X64
#    define SPLIT_OLED_ENABLE
#    define OLED_FONT_H  "./lib/glcdfont.c"
#endif


// ┌─────────────────────────────────────────────────┐
// │ r g b   l e d s                                 │
// └─────────────────────────────────────────────────┘ 

//#define WS2812_DI_PIN GP0
#define RGBLED_NUM 42
#define RGBLED_SPLIT { 21, 21 }
#define RGB_MATRIX_LED_COUNT RGBLED_NUM

#ifdef RGB_MATRIX_ENABLE
#    define RGB_MATRIX_STARTUP_MODE RGB_MATRIX_BREATHING
#    define SPLIT_TRANSPORT_MIRROR true
#    define DRIVER_LED_TOTAL 42 // Number of LEDs
#    define RGB_MATRIX_SPLIT { 21, 21 }
#    define RGB_MATRIX_TIMEOUT 120000
#    define RGB_MATRIX_SLEEP
#    define RGB_MATRIX_LED_FLUSH_LIMIT 16
#    define RGB_MATRIX_MAXIMUM_BRIGHTNESS 255
#    define RGB_MATRIX_STARTUP_HUE 299
#    define RGB_MATRIX_DEFAULT_ON true
#    define RGB_MATRIX_DEFAULT_SAT 255
#    define RGB_MATRIX_DEFAULT_SPD 127
#    define RGB_MATRIX_STARTUP_VAL RGB_MATRIX_MAXIMUM_BRIGHTNESS
#    define RGB_DISABLE_WHEN_USB_SUSPENDED
#    define RGB_MATRIX_KEYPRESSES
#endif 


// ┌─────────────────────────────────────────────────┐
// │ a u d i o                                       │
// └─────────────────────────────────────────────────┘

#define AUDIO_PWM_DRIVER PWMD4
#define AUDIO_PWM_CHANNEL RP2040_PWM_CHANNEL_B
#define AUDIO_STATE_TIMER GPTD4
#define AUDIO_PIN GP9
#define AUDIO_VOICES
#define AUDIO_DAC_SAMPLE_MAX 4095U
#define AUDIO_VOICE_DEFAULT butts_fader

#ifdef AUDIO_ENABLE     
#    define KLOR_SOUND W__NOTE(_DS0), W__NOTE(_DS1), H__NOTE(_DS2), H__NOTE(_DS3), Q__NOTE(_DS4), Q__NOTE(_DS5), E__NOTE(_DS6), E__NOTE(_DS7), S__NOTE(_DS8), Q__NOTE(_GS0)
#    define STARTUP_SONG SONG(KLOR_SOUND)
#    define BYE_SOUND H__NOTE(_DS4), H__NOTE(_DS3), W__NOTE(_DS1)
#    define GOODBYE_SONG SONG(BYE_SOUND)
#    define DEFAULT_LAYER_SONGS \
        { SONG(QWERTY_SOUND), SONG(COLEMAK_SOUND) }
#endif 


// ┌─────────────────────────────────────────────────┐
// │ h a p t i c   f e e d b a c k                   │
// └─────────────────────────────────────────────────┘ 

#ifdef HAPTIC_ENABLE
#    define FB_ERM_LRA 1
#    define FB_BRAKEFACTOR 3 // For 1x:0, 2x:1, 3x:2, 4x:3, 6x:4, 8x:5, 16x:6, Disable Braking:7 
#    define FB_LOOPGAIN 1 // For  Low:0, Medium:1, High:2, Very High:3 
#    define RATED_VOLTAGE 2
#    define V_PEAK 2.8
#    define V_RMS 2.0 
#    define F_LRA 150 // resonance freq 
#    define DRV_GREETING       alert_750ms
#    define SPLIT_HAPTIC_ENABLE
#    define DRV2605L_DEFAULT_MODE 4
#endif


// ┌─────────────────────────────────────────────────┐
// │ t r a c k b a l l                               │
// └─────────────────────────────────────────────────┘ 

#ifdef POINTING_DEVICE_ENABLE
#    define PAW3204_SCLK_PIN GP3
#    define PAW3204_SDIO_PIN GP2
#    define POINTING_DEVICE_AUTO_MOUSE_ENABLE
#    define AUTO_MOUSE_DELAY 300
#endif

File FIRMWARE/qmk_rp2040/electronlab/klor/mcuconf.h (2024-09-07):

/*
    ChibiOS - Copyright (C) 2006..2021 Giovanni Di Sirio

    Licensed under the Apache License, Version 2.0 (the "License");
    you may not use this file except in compliance with the License.
    You may obtain a copy of the License at

        http://www.apache.org/licenses/LICENSE-2.0

    Unless required by applicable law or agreed to in writing, software
    distributed under the License is distributed on an "AS IS" BASIS,
    WITHOUT WARRANTIES OR CONDITIONS OF ANY KIND, either express or implied.
    See the License for the specific language governing permissions and
    limitations under the License.
*/

#ifndef MCUCONF_H
#define MCUCONF_H

/*
 * RP2040_MCUCONF drivers configuration.
 *
 * IRQ priorities:
 * 3...0        Lowest...Highest.
 *
 * DMA priorities:
 * 0...1        Lowest...Highest.
 */

#define RP2040_MCUCONF

/*
 * HAL driver system settings.
 */
#define RP_NO_INIT                          FALSE
#define RP_CORE1_START                      FALSE
#define RP_CORE1_VECTORS_TABLE              _vectors
#define RP_CORE1_ENTRY_POINT                _crt0_c1_entry
#define RP_CORE1_STACK_END                  __c1_main_stack_end__

/*
 * IRQ system settings.
 */
#define RP_IRQ_SYSTICK_PRIORITY             2
#define RP_IRQ_TIMER_ALARM0_PRIORITY        2
#define RP_IRQ_TIMER_ALARM1_PRIORITY        2
#define RP_IRQ_TIMER_ALARM2_PRIORITY        2
#define RP_IRQ_TIMER_ALARM3_PRIORITY        2
#define RP_IRQ_ADC1_PRIORITY                3
#define RP_IRQ_UART0_PRIORITY               3
#define RP_IRQ_UART1_PRIORITY               3
#define RP_IRQ_SPI0_PRIORITY                2
#define RP_IRQ_SPI1_PRIORITY                2
#define RP_IRQ_USB0_PRIORITY                3
#define RP_IRQ_I2C0_PRIORITY                2
#define RP_IRQ_I2C1_PRIORITY                2
#define RP_IRQ_RTC_PRIORITY                 3

/*
 * ADC driver system settings.
 */
#define RP_ADC_USE_ADC1                     TRUE

/*
 * SIO driver system settings.
 */
#define RP_SIO_USE_UART0                    FALSE
#define RP_SIO_USE_UART1                    FALSE

/*
 * SPI driver system settings.
 */
#define RP_SPI_USE_SPI0                     TRUE
#define RP_SPI_USE_SPI1                     FALSE
#define RP_SPI_SPI0_RX_DMA_CHANNEL          RP_DMA_CHANNEL_ID_ANY
#define RP_SPI_SPI0_TX_DMA_CHANNEL          RP_DMA_CHANNEL_ID_ANY
#define RP_SPI_SPI1_RX_DMA_CHANNEL          RP_DMA_CHANNEL_ID_ANY
#define RP_SPI_SPI1_TX_DMA_CHANNEL          RP_DMA_CHANNEL_ID_ANY
#define RP_SPI_SPI0_DMA_PRIORITY            1
#define RP_SPI_SPI1_DMA_PRIORITY            1
#define RP_SPI_DMA_ERROR_HOOK(spip)

/*
 * PWM driver system settings.
 */
#define RP_PWM_USE_PWM0                     FALSE
#define RP_PWM_USE_PWM1                     FALSE
#define RP_PWM_USE_PWM2                     FALSE
#define RP_PWM_USE_PWM3                     FALSE
#define RP_PWM_USE_PWM4                     TRUE
#define RP_PWM_USE_PWM5                     FALSE
#define RP_PWM_USE_PWM6                     FALSE
#define RP_PWM_USE_PWM7                     FALSE
#define RP_PWM_IRQ_WRAP_NUMBER_PRIORITY     3

/*
 * I2C driver system settings.  
 */
#define RP_I2C_USE_I2C0                     FALSE
#define RP_I2C_USE_I2C1                     TRUE
#define RP_I2C_BUSY_TIMEOUT                 50
#define RP_I2C_ADDRESS_MODE_10BIT           FALSE

/*
 * USB driver system settings.
 */
#define RP_USB_USE_USBD0                    TRUE
#define RP_USB_FORCE_VBUS_DETECT            TRUE
#define RP_USE_EXTERNAL_VBUS_DETECT         FALSE
#define RP_USB_USE_ERROR_DATA_SEQ_INTR      FALSE

#endif /* MCUCONF_H */

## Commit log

2024-07-09 modifié : PCB/klor1_3/KLOR.pretty/MJ-4PP-9.kicad_mod modifié : PCB/klor1_3/fp-info-cache modifié : PCB/klor1_3/gerbers/klor1_3-B_Cu.gbl modifié : PCB/klor1_3/gerbers/klor1_3-B_Mask.gbs modifié : PCB/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
    [klor1_3-B_Mask.gbs, klor1_3-B_Paste.gbp, klor1_3-B_Silkscreen.gbo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]
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2024-07-25 modifié : PCB/klor1_3/KLOR.pretty/SK6812MINI_and_cherry.kicad_mod nouveau fichier : PCB/klor1_3/klor1_3-backups/klor1_3-2024-07-23_162032.zip modifié : PCB/klor1_3/klor1_3.kicad_pro nouveau fichier :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
    [Base-Konrad.stl, BaseWithTenting-Konrad.stl, EncoderInsert-16mm.stl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]
2024-07-25 nouveau fichier : PCB/klor1_4/klor1_4-backups/klor1_4-2024-07-25_133230.zip nouveau fichier : docs/images/Klor_1.4_picture1.png nouveau fichier : docs/images/Klor_1.4_picture2.png supprimé : PCB/klor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
2024-07-25 nouveau fichier : PCB/klor1_4/_autosave-klor1_4.kicad_pcb modifié : PCB/klor1_4/gerbers/gerbers.zip modifié : PCB/klor1_4/gerbers/klor1_4-B_Cu.gbl modifié : PCB/klor1_4/gerbers/klor1_4-B_Mask.gbs mod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
    [klor1_4-B_Cu.gbl, klor1_4-B_Mask.gbs, klor1_4-B_Paste.gbp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]
2024-07-25 nouveau fichier : FIRMWARE/build.yaml nouveau fichier : FIRMWARE/config/boards/shields/klor/Kconfig.defconfig nouveau fichier : FIRMWARE/config/boards/shields/klor/Kconfig.shield nouveau fichier : FI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
2024-07-25 modifié : PCB/klor1_3/klor1_3.kicad_prl modifié : PCB/klor1_4/klor1_4.kicad_pcb modifié : PCB/klor1_4/klor1_4.kicad_prl modifié : PCB/klor1_4/klor1_4.kicad_pro supprimé : PCB/klor1_4/~klor1_3.kicad_p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
2024-07-26 modifié : gerbers.zip modifié : klor1_4-B_Cu.gbl modifié : klor1_4-B_Mask.gbs modifié : klor1_4-B_Paste.gbp modifié : klor1_4-B_Silkscreen.gbo modifié : klor1_4-Edge_Cuts.gm1 modifié : klor1_4-F_Cu.g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
    [klor1_4-B_Cu.gbl, klor1_4-B_Mask.gbs, klor1_4-B_Paste.gbp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]
2024-07-30 modifié : FIRMWARE/config/boards/shields/klor/boards/nice_nano_v2.overlay modifié : FIRMWARE/config/boards/shields/klor/klor.dtsi modifié : FIRMWARE/config/boards/shields/klor/klor_common.dtsi modifi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
2024-07-30 modifié : PCB/klor1_4/KLOR.pretty/Buzzer_Mallory_AST1109MLTRQ_reversible.kicad_mod modifié : PCB/klor1_4/KLOR.pretty/Diode_SOD123.kicad_mod modifié : PCB/klor1_4/KLOR.pretty/SK6812MINI_and_cherry_1.k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
2024-07-30 modifié : PCB/klor1_4/gerbers/gerbers.zip modifié : PCB/klor1_4/gerbers/klor1_4-B_Cu.gbl modifié : PCB/klor1_4/gerbers/klor1_4-B_Mask.gbs modifié : PCB/klor1_4/gerbers/klor1_4-B_Paste.gbp modifié : P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
    [klor1_4-B_Cu.gbl, klor1_4-B_Mask.gbs, klor1_4-B_Paste.gbp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]
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2024-08-09 nouveau fichier : PCB/Alternate DIY Haptic Module/Gerber_Haptic-Module_Haptic-Module_2024-08-09.zip nouveau fichier : case/Alternate Case Design/535004-case-designs-for-klor-polydactyl-konrad-yubitsu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
    [Base-Konrad.stl, BaseWithTenting-Konrad.stl, EncoderInsert-16mm.stl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]
2024-08-09 Update README.md
    Inclusion of DIY haptic module. Correction of PCB for stock module
2024-08-09 supprimé : ../PCB/klor1_3/klor1_3-backups/klor1_3-2024-07-06_111804.zip supprimé : ../PCB/klor1_3/klor1_3-backups/klor1_3-2024-07-06_112832.zip supprimé : ../PCB/klor1_3/klor1_3-backups/klor1_3-2024-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
2024-08-09 supprimé : case-designs-for-klor-polydactyl-konrad-yubitsume-and-saegewerk-model_files/535004-case-designs-for-klor-polydactyl-konrad-yubitsume-and-saegewerk-2240062f-93fd-4992-ab70-c1e3f6eb6469.pdf 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
    [Base-Konrad.stl, BaseWithTenting-Konrad.stl, EncoderInsert-16mm.stl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]
2024-08-09 modifié : ../PCB/klor1_4/fp-info-cache modifié : ../PCB/klor1_4/gerbers/gerbers.zip modifié : ../PCB/klor1_4/gerbers/klor1_4-B_Cu.gbl modifié : ../PCB/klor1_4/gerbers/klor1_4-B_Mask.gbs modifié : ../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
    [klor1_4-B_Cu.gbl, klor1_4-B_Mask.gbs, klor1_4-B_Paste.gbp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]
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2024-08-09 supprimé : ../PCB/klor1_4/klor1_4-backups/klor1_4-2024-07-25_161157.zip supprimé : ../PCB/klor1_4/klor1_4-backups/klor1_4-2024-07-25_161736.zip supprimé : ../PCB/klor1_4/klor1_4-backups/klor1_4-2024-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
2024-08-27 nouveau fichier : PCB/klor1_4_LP_KS33/KLOR.pretty/Buzzer_Mallory_AST1109MLTRQ_reversible.kicad_mod nouveau fichier : PCB/klor1_4_LP_KS33/KLOR.pretty/Diode_SOD123.kicad_mod nouveau fichier : PCB/klor1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
    [klor1_4-B_Cu.gbl, klor1_4-B_Mask.gbs, klor1_4-B_Paste.gbp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]
2024-08-27 modifié : PCB/klor1_3/gerbers/gerbers.zip modifié : PCB/klor1_3/gerbers/klor1_3-B_Cu.gbl modifié : PCB/klor1_3/gerbers/klor1_3-B_Mask.gbs modifié : PCB/klor1_3/gerbers/klor1_3-B_Paste.gbp modifié : P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
    [klor1_3-B_Mask.gbs, klor1_3-B_Paste.gbp, klor1_3-B_Silkscreen.gbo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]
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2024-08-28 supprimé : FIRMWARE/Ready-to-flash/qmk-RP2040/klor_default.uf2 modifié : FIRMWARE/qmk_rp2040/klor/config.h modifié : FIRMWARE/qmk_rp2040/klor/keyboard.json modifié : FIRMWARE/qmk_rp2040/klor/keymaps/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
    [klor1_4-B_Cu.gbl, klor1_4-B_Mask.gbs, klor1_4-B_Paste.gbp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]
2024-08-28 Update CHANGELOG.md
    Correction of the wiring error of the 1.3 original design for serial communication. Correction was made to both 1.4 versions but NOT on the 1.3 version provided on this fork.
2024-08-29 renommé : FIRMWARE/Ready-to-flash/qmk-RP2040/klor_default_mirror_serial.uf2 -> FIRMWARE/Ready-to-flash/qmk-RP2040/klor_default.uf2 supprimé : FIRMWARE/Ready-to-flash/qmk-RP2040/klor_default_crossed_s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
    [klor1_4-B_Cu.gbl, klor1_4-B_Mask.gbs, klor1_4-B_Paste.gbp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]
2024-08-29 modifié : PCB/klor1_4_LP_KS33/KLOR.pretty/MJ-4PP-9.kicad_mod supprimé : PCB/klor1_4_LP_KS33/README.md modifié : PCB/klor1_4_LP_KS33/fp-info-cache modifié : PCB/klor1_4_LP_KS33/gerbers/gerbers.zip mod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
    [klor1_4-B_Cu.gbl, klor1_4-B_Mask.gbs, klor1_4-B_Paste.gbp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]
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2024-09-03 nouveau fichier : PCB/klor1_4_LP_KS33/KLOR.pretty/KS33_Symetrical.kicad_mod modifié : PCB/klor1_4_LP_KS33/fp-info-cache modifié : PCB/klor1_4_LP_KS33/gerbers/gerbers.zip renommé : PCB/klor1_4_LP_KS33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
    [klor1_4-B_Cu.gbl, klor1_4-B_Mask.gbs, klor1_4-B_Paste.gbp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]
2025-04-15 Single for handmade pcb, start
    [klor1_4-B_Cu.gbl, klor1_4-B_Mask.gbs, klor1_4-B_Paste.gbp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]
2025-04-15 single mcu
    [klor1_4.kicad_pcb]
2025-04-15 single 2504151724
    [klor1_4.kicad_pcb]
2025-04-18 tümünü temizlemeden önce
    [klor1_4.kicad_pcb]
2025-04-18 left done
    [klor1_4-B_Cu.gbl, klor1_4-B_Mask.gbs, klor1_4-B_Paste.gbp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]

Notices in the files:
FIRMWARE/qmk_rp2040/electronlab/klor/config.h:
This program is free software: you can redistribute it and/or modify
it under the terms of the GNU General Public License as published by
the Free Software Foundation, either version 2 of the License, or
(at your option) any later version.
